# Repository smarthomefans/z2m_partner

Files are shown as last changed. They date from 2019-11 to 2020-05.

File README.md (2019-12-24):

# [中文文档](https://bbs.iobroker.cn/t/topic/882)

# z2m hardware module

This is hardware module for [iobroker.zigbee](https://github.com/ioBroker/ioBroker.zigbee) and [zigbee2mqtt](https://github.com/Koenkk/zigbee2mqtt) or [Zigbee to Tasmota](https://github.com/arendst/Tasmota/wiki/Zigbee).  
If you can speak Chinese and be interested with this project, please look at this [post](https://bbs.iobroker.cn/t/topic/882/33) in [ioBroker China BBS](https://bbs.iobroker.cn/)

## **V2P1 version is ready to ship**

## What's the difference

- Use [E18-MS1PA1-IPX](http://www.ebyte.com/en/product-view-news.aspx?id=123) zigbee module. 20dBm power can make sure zigbee net work signal is strong.
- Add an ESP8266 module. Give you another option that can connect zigbee module though wifi-to-serial (I was using this [project](https://github.com/smarthomefans/ESP32-Serial-Bridge)).
If your machine running smarthome platform, such as ioBroker or homeassistant, is put in a hidden corner, for better signal coverage, you can put your zigbee module in some where else.
- ESP8266 connected to E18 firmware download pins, give you a chance that can update E18 though ESP8266, no need to use CC-DEBUG.
- There will be 4 options for different TTY connection:
  - USB TTY <==> ESP 8266 TTY. This option is used for download firmware for E18.
  - USB TTY <==> E18 TTY. If you can connect your module though USB wire, this is more stable.
  - USB TTY <==> ESP 8266 debug port. ESP 8266 TTY <==> E18 TTY. Connect though wifi, and you can capture debug infomation though USB TTY.
  - ESP 8266 TTY <==> E18 TTY. Connect though TTY.

## Hardware module images

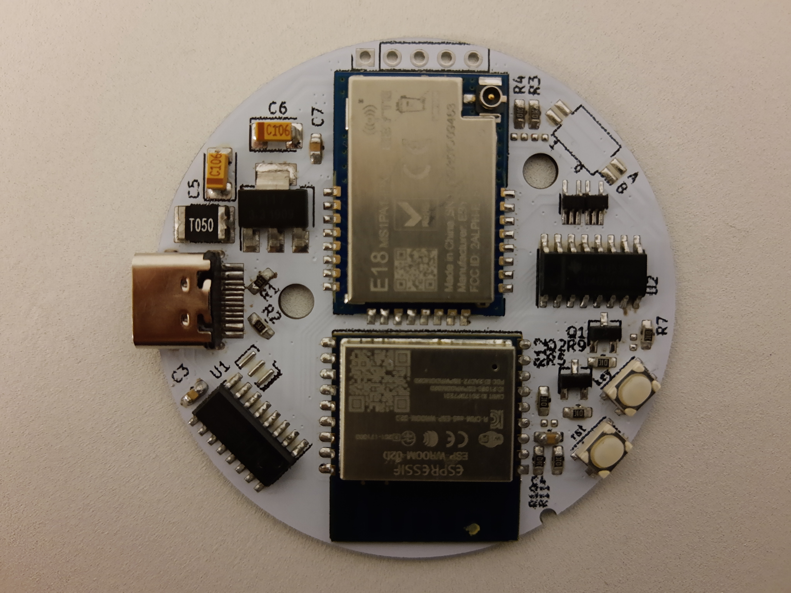
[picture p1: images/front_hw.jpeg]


## 3D cover

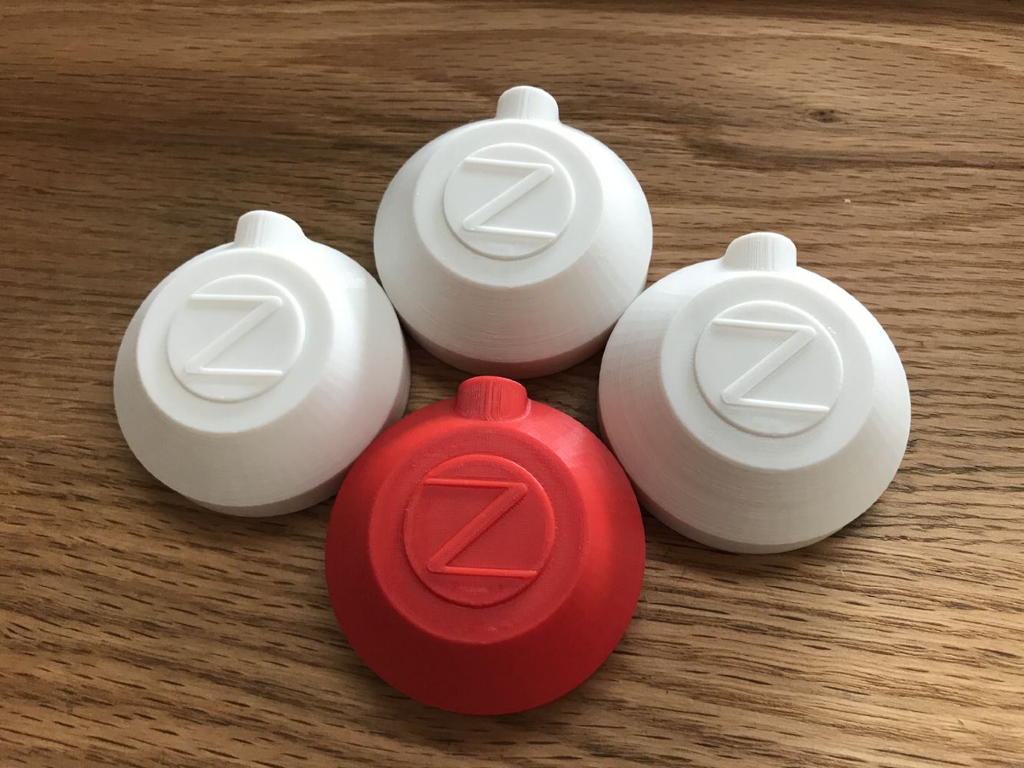
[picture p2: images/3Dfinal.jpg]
cave


## [SCH](https://github.com/smarthomefans/z2m_partner/raw/master/project/z2m_partner.pdf) preview
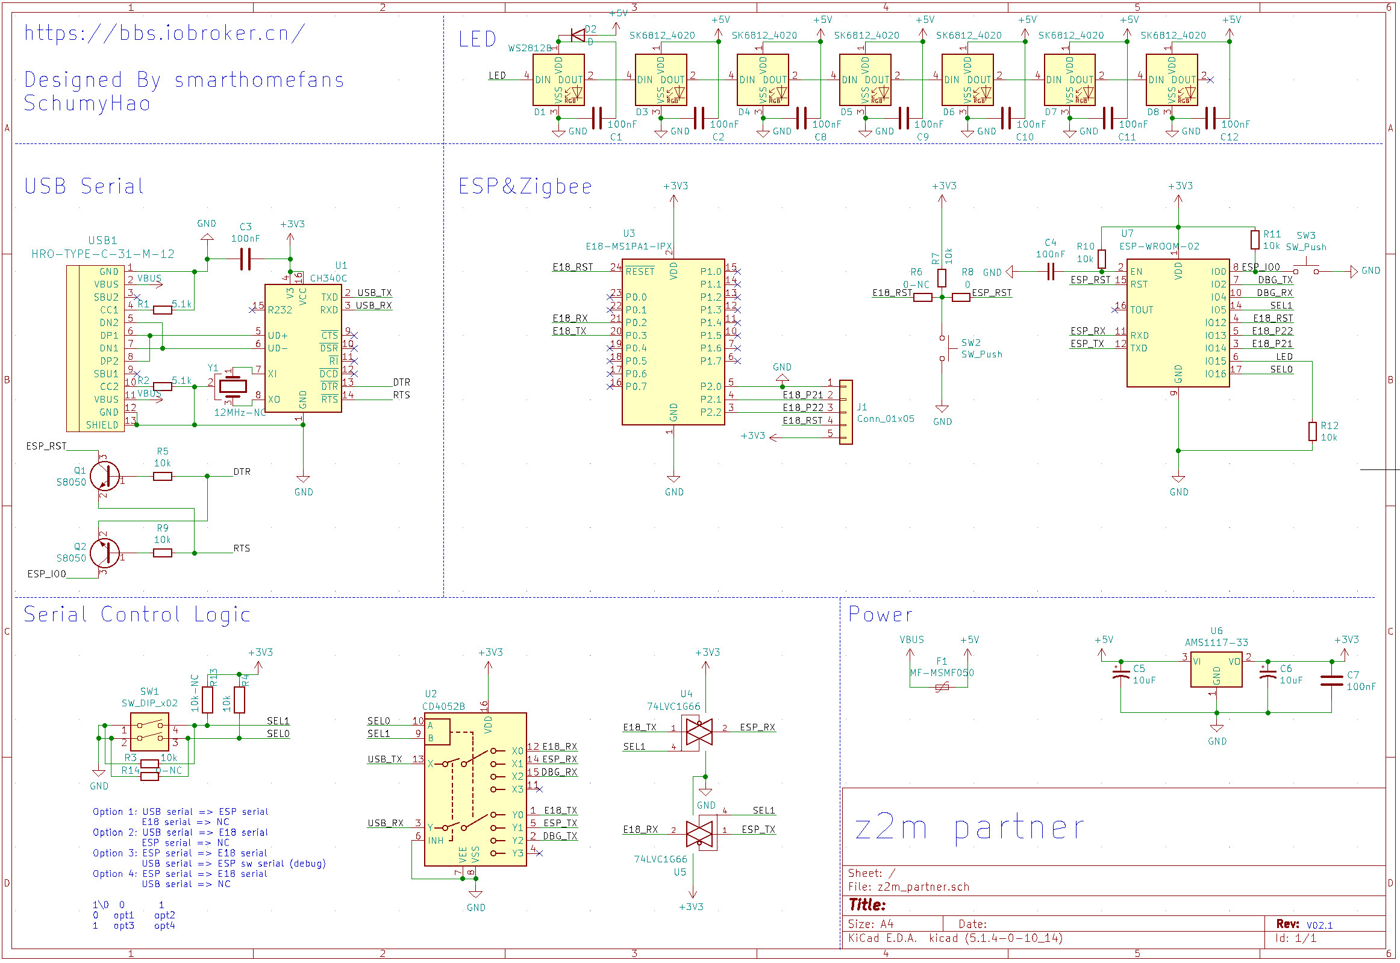
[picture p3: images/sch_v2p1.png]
sch view


## PCB preview

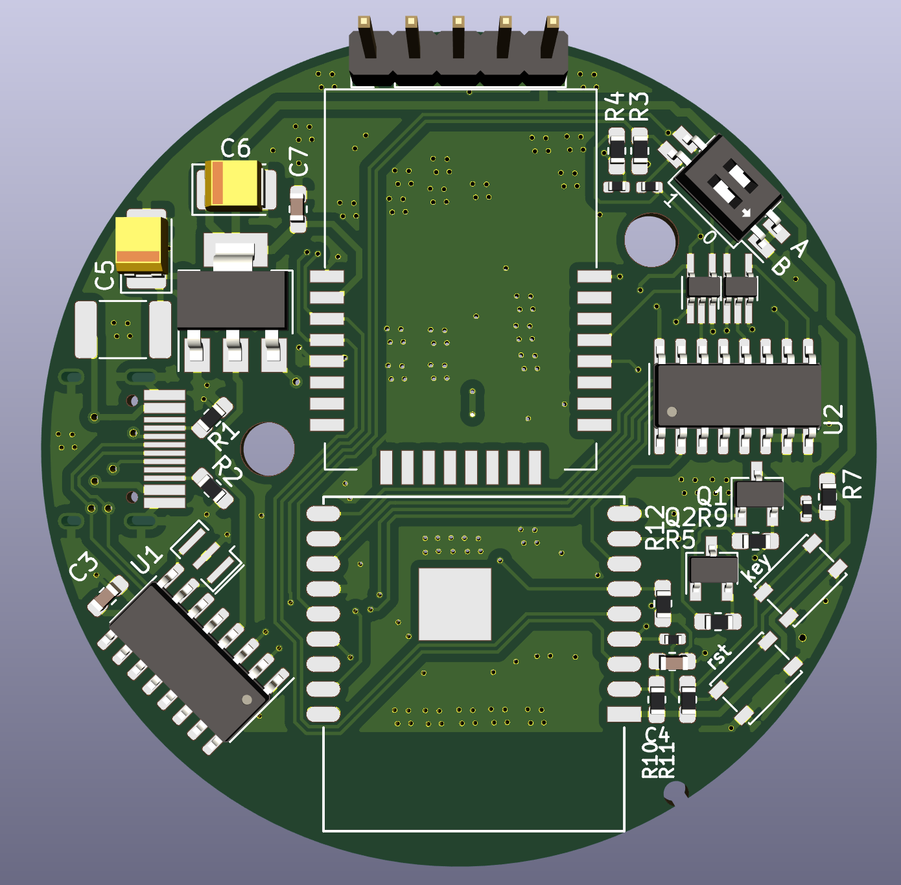
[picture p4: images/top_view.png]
top view

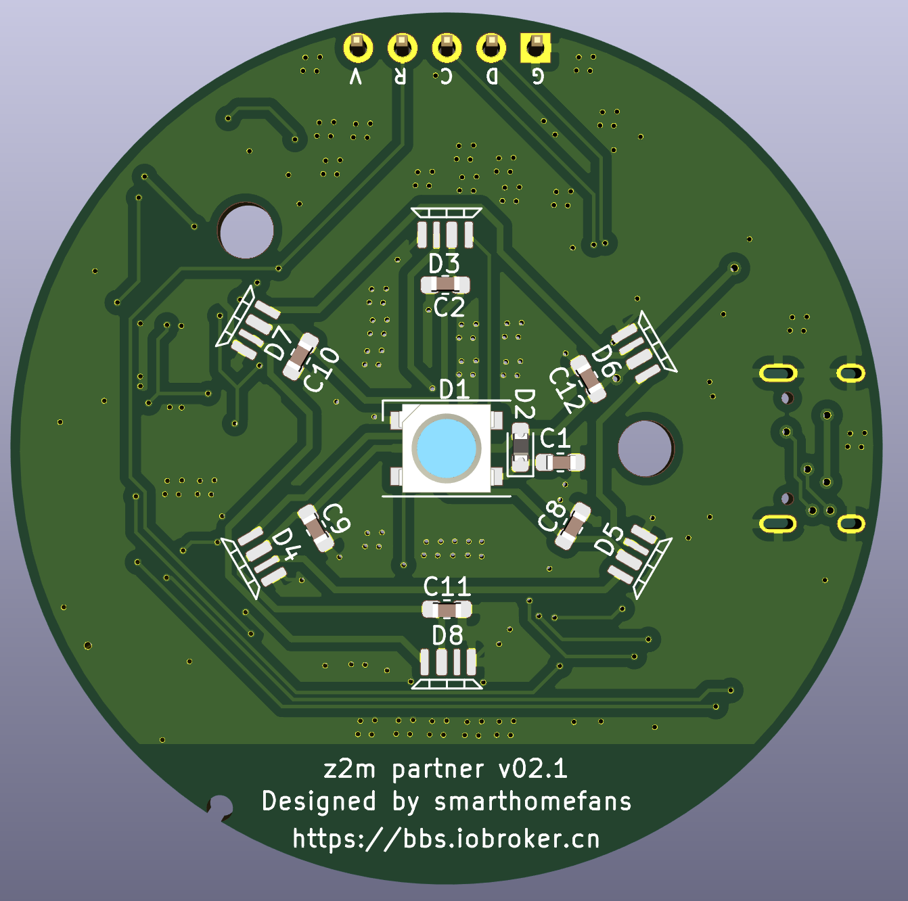
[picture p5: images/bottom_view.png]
bottom view


## BOM list
[BOM](https://github.com/smarthomefans/z2m_partner/blob/master/documents/bom.md) can get from here.

## Thanks to

- [modkam](https://modkam.ru/), [kirovilya](https://github.com/kirovilya), [Koenkk](https://github.com/Koenkk).

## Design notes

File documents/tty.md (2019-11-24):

# Z2M USB串口复用控制

## V01版本

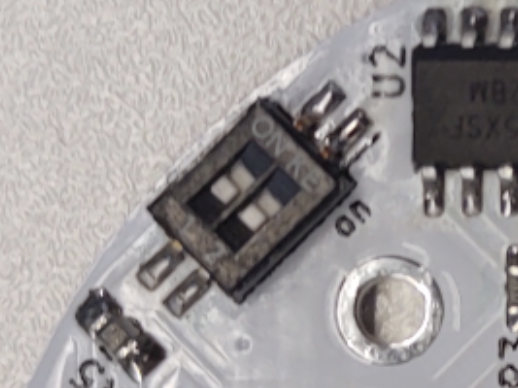
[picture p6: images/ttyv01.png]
switchv01


### 开关名称和状态定义

- 定义开关为上、下两个开关.
- 开关分别有左、右两种状态.

(就是别看板子上的丝印了)

### 工作模式对照表

-|上左|上右
---|---|---
下左|ESP连Zigbee, USB串口没有输出|ESP连Zigbee, USB串口输出调试信息
下右|USB串口连接Zigbee|USB串口连接ESP

## V02版本(未测试)

此版本目的是要不需要用户控制, 完全用ESP模块来控制串口复用状态.
所以, 请不焊接SW1, R13, R14, R3, R4.  
如果焊接了SW1, 也别焊接R3, R4, 并且保持SW1的两个开关都处于左测.

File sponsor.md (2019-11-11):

# Thanks to everyone who loves this project

# 感谢每一个喜欢这个项目的人

- li***36   6.66￥

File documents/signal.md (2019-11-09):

# E18系列模组信号测量结果

我使用频谱仪实际测量了不同的固件情况下, E18两款模组[E18-MS1PA1-IPX](http://www.ebyte.com/en/product-view-news.aspx?id=123)和[E18-2G4Z27SI](http://www.ebyte.com/en/product-view-news.aspx?id=522)发射时实际功率值.

在[Koenkk zigbee2mqtt](https://github.com/Koenkk/Z-Stack-firmware/tree/master/coordinator/Z-Stack_Home_1.2)使用的修订版ZNP固件中, 默认提供的CC2530+CC2592固件, 设置TX发射功率为[TX_PWR_PLUS_19](https://github.com/Koenkk/Z-Stack-firmware/blob/master/coordinator/Z-Stack_Home_1.2/firmware.patch#L328). 但是CC2592的手册说明此PA是可以21dBm发射的.

我发现TI源码中, 设置Tx发射功率的enum数据类型最大只定义到了19dBm, 揣测可能Koenkk就是使用了默认的最大值, 而没有根据不同PA进行设置.

我修改ZNP源码并编译, 得到了不同情况下的发射信号功率图.

## 默认固件

[E18-MS1PA1-IPX](http://www.ebyte.com/en/product-view-news.aspx?id=123)和[E18-2G4Z27SI](http://www.ebyte.com/en/product-view-news.aspx?id=522)情况一样. 实测发射功率为14.202dBm.
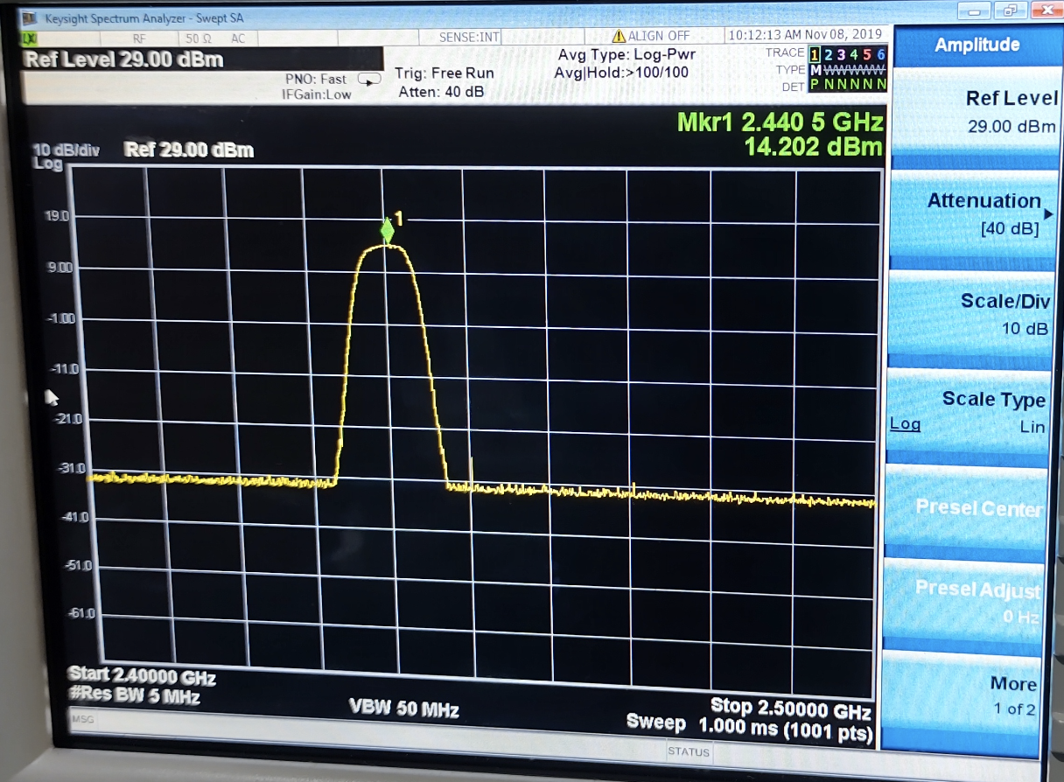
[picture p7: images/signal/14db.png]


## 修改21dBm

[E18-MS1PA1-IPX](http://www.ebyte.com/en/product-view-news.aspx?id=123)模组, 设置发射功率为2592最大功率21dBm. 代码修改如下:

```C
-      ZMacSetTransmitPower(TX_PWR_PLUS_19);
+      ZMacSetTransmitPower(21);
```

实测发射功率18.495dBm.
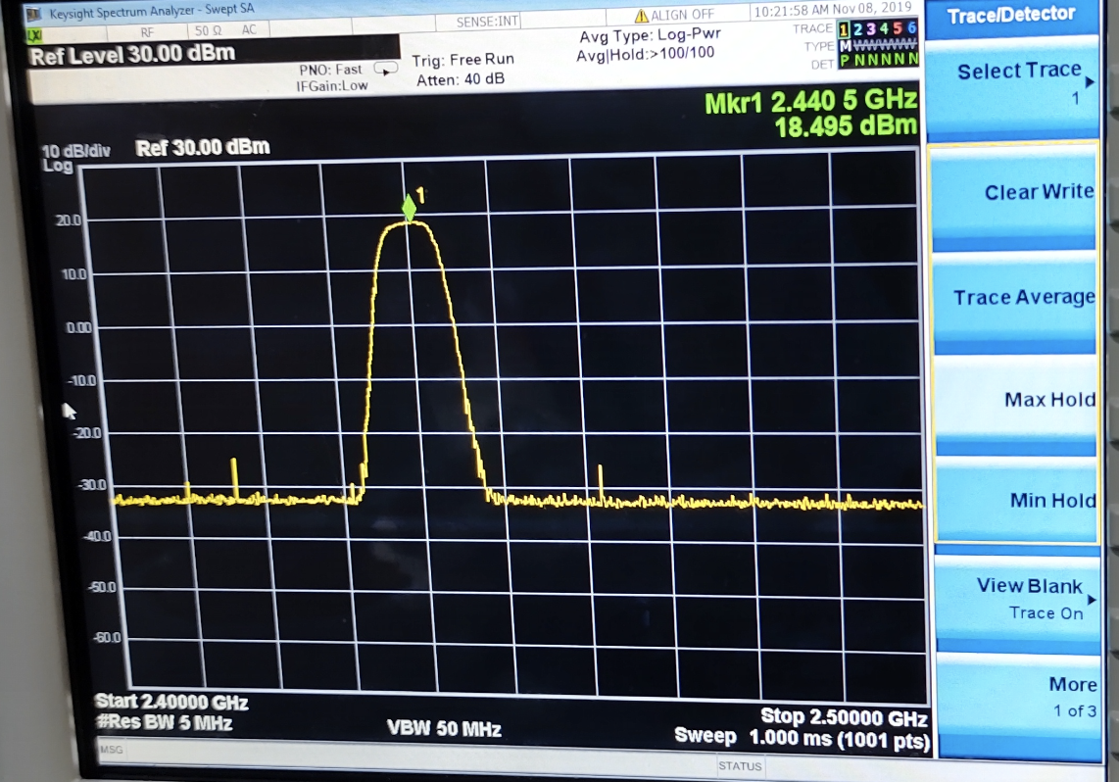
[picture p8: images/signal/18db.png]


## 修改27dBm

[E18-2G4Z27SI](http://www.ebyte.com/en/product-view-news.aspx?id=522)模组, 设置模组最大功率27dBm. 代码修改如下:

```C
-      ZMacSetTransmitPower(TX_PWR_PLUS_19);
+      ZMacSetTransmitPower(27);
```

实测发射功率26.809dBm.
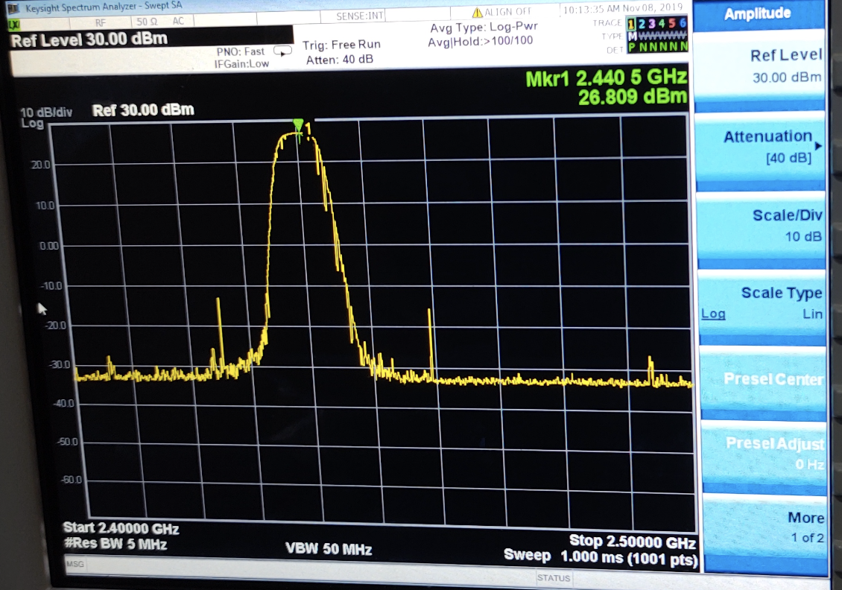
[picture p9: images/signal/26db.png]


## 总结

从频谱仪的实测结果来看, 要达到最大发射功率的话, 必须要修改固件源码才行. 我并不是专业硬件人员, 对于这个结果, 我又两点疑问:

1. 最大发射功率情况下, 明显能看到谐波的毛刺, 这个毛刺会不会对数据有干扰?
2. 修改的都是最大发射功率, 但是实际使用时, zigbee传感器会向网关发数据, 这时候网关是接收状态. 我们没办法修改小米等zigbee传感器, 是不是在这个情况下, 只增大网关的发射功率, 对双向传输的zigbee协议, 是不是太大帮助?

如果有专业人士可以帮忙解答, 麻烦提issue回答一下, 先表感谢.

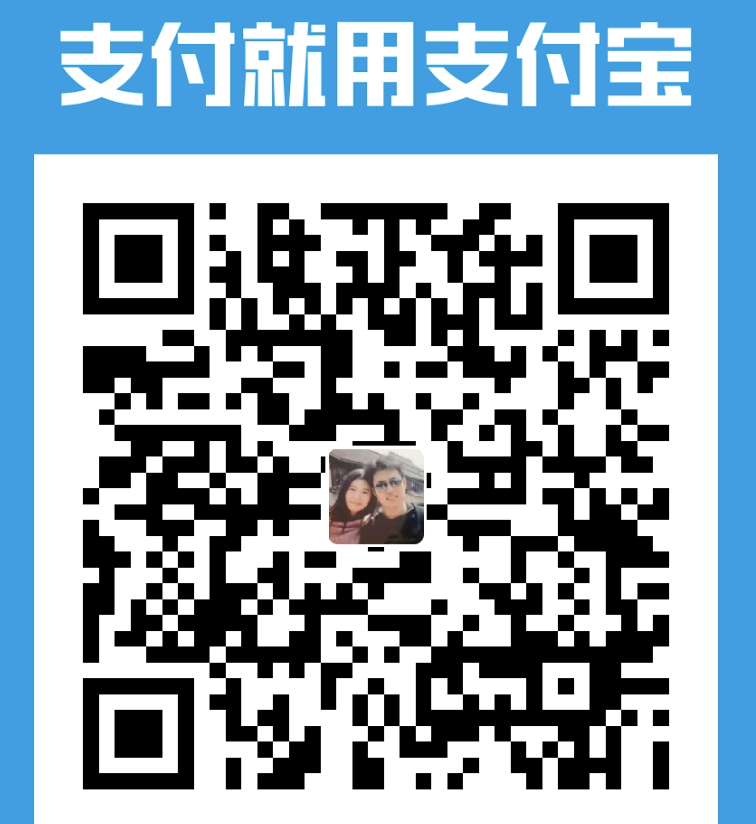
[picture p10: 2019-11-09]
images/pay/alipay.png

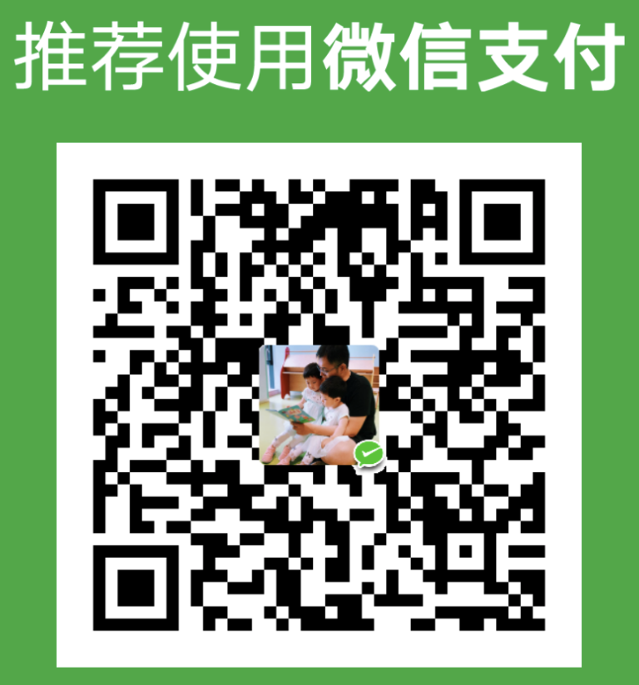
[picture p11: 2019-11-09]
images/pay/wechat.png

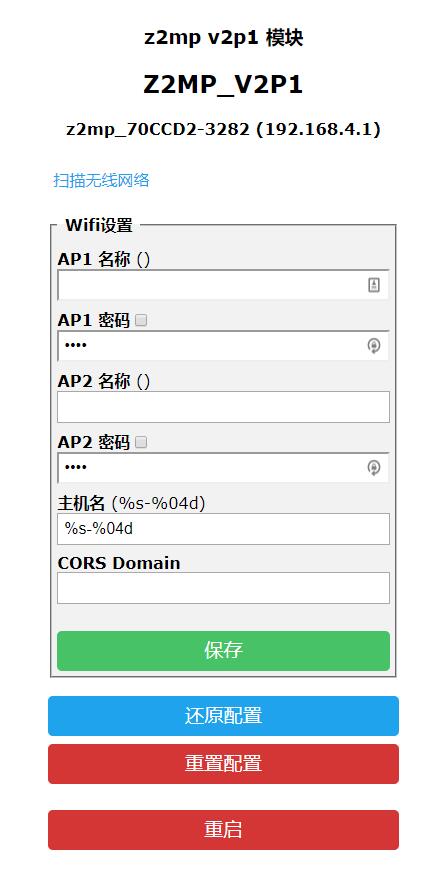
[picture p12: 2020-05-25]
images/tasmota/wifi_config.jpg

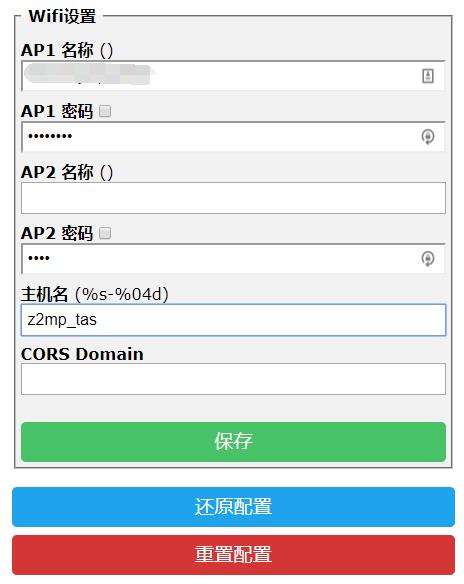
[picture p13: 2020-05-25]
images/tasmota/wifi_config2.jpg

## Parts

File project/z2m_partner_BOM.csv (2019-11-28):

Comment | Description | Designator | Footprint | LibRef | Pins | Quantity | PartNumber | url
100nF | desc | C3,C4,C7, | C_0603_1608Metric_Pad1.05x0.95mm_HandSolder | libref | 2 | 3 |  | ~
10uF | desc | C5,C6, | CP_EIA-3528-21_Kemet-B_Pad1.50x2.35mm_HandSolder | libref | 2 | 2 |  | ~
MF-MSMF050 | desc | F1, | Fuse_1812_4532Metric_Pad1.30x3.40mm_HandSolder | libref | 2 | 1 |  | ~
S8050 | desc | Q1,Q2, | TSOT-23 | libref | 3 | 2 |  | ~
5.1k | desc | R1,R2, | R_0603_1608Metric_Pad1.05x0.95mm_HandSolder | libref | 2 | 2 |  | ~
10k-NC | desc | R13, | R_0402_1005Metric | libref | 2 | 1 |  | ~
10k | desc | R4,R7,R10,R11,R12,R5,R9,R3, | R_0603_1608Metric_Pad1.05x0.95mm_HandSolder | libref | 2 | 8 |  | ~
0-NC | desc | R6,R14, | R_0402_1005Metric | libref | 2 | 2 |  | ~
0 | desc | R8, | R_0402_1005Metric | libref | 2 | 1 |  | ~
SW_DIP_x02 | desc | SW1, | SW_DIP_SPSTx02_Slide_Copal_CHS-02B_W7.62mm_P1.27mm | libref | 4 | 1 |  | ~
SW_Push | desc | SW2,SW3, | SW_SPST_PTS810 | libref | 4 | 2 |  | ~
CH340C | desc | U1, | SOIC-16_3.9x9.9mm_P1.27mm | libref | 16 | 1 |  | http://www.datasheet5.com/pdf-local-2195953
CD4052B | desc | U2, | SOIC-16_3.9x9.9mm_P1.27mm | libref | 16 | 1 |  | http://www.ti.com/lit/ds/symlink/cd4052b.pdf
E18-MS1PA1-IPX | desc | U3, | E18-MS1PA1-IPX | libref | 24 | 1 |  | http://www.cdebyte.com/en/downpdf.aspx?id=122
74LVC1G66 | desc | U4,U5, | SOT-353_SC-70-5_Handsoldering | libref | 5 | 2 |  | http://www.ti.com/lit/sg/scyt129e/scyt129e.pdf
AMS1117-33 | desc | U6, | SOT-223-3_TabPin2 | libref | 4 | 1 |  | http://www.diodes.com/datasheets/AP1117.pdf
ESP-WROOM-02 | desc | U7, | ESP-13-WROOM-02 | libref | 19 | 1 |  | https://www.espressif.com/sites/default/files/documentation/0c-esp-wroom-02_datasheet_en.pdf
12MHz-NC | desc | Y1, | Resonator_SMD_muRata_CSTxExxV-3Pin_3.0x1.1mm | libref | 3 | 1 |  | ~
100nF | desc | C1,C2,C8,C9,C10,C11,C12, | C_0603_1608Metric_Pad1.05x0.95mm_HandSolder | libref | 2 | 7 |  | ~
WS2812B | desc | D1, | LED_WS2812B_PLCC4_5.0x5.0mm_P3.2mm | libref | 4 | 1 |  | https://cdn-shop.adafruit.com/datasheets/WS2812B.pdf
D | desc | D2, | D_0603_1608Metric_Pad1.05x0.95mm_HandSolder | libref | 2 | 1 |  | ~
SK6812_4020 | desc | D3,D4,D5,D6,D7,D8, | SK6812_4020 | libref | 4 | 6 |  | https://cdn-shop.adafruit.com/datasheets/WS2812B.pdf
Through Hole Items
Conn_01x05 | desc | J1, | PinHeader_1x05_P2.54mm_Vertical | libref | 5 | 1 |  | ~
MountingHole_3.2mm_M3_ISO14580 | desc | REF**,REF**, | MountingHole_3.2mm_M3_ISO14580 | libref | 1 | 2
HRO-TYPE-C-31-M-12 | desc | USB1, | HRO-TYPE-C-31-M-12-HandSoldering | libref | 18 | 1

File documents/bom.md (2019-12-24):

## BOM单

### 做WiFi/USB有线接入的Zigbee网关

名称|封装|数值|数量|标号|立创商城货号
---|---|---|---|---|---
贴片钽电容|TypeB|10uF|2|C5, C6|[C128257](https://item.szlcsc.com/139542.html)
贴片电容|0603|100nF|3|C3, C4, C7|[C149620](https://item.szlcsc.com/160954.html)
自恢复限流保险|1812|MF-MSMF050|1|F1|[C17313](https://item.szlcsc.com/17998.html)
贴片电阻|0603|5.1k|2|R1, R2|[C26000](https://item.szlcsc.com/26743.html)
贴片电阻|0603|10k|8|R3, R4, R5, R7, R9-R12|[C15401](https://item.szlcsc.com/16079.html)
微动开关|SW_SPST_PTS810|SW_Push|2|SW2, SW3|[C221896](https://item.szlcsc.com/222326.html)
USB串口芯片|SOP16|CH340C|1|U1|[C84681](https://item.szlcsc.com/85852.html)
模拟开关芯片|SOP16|CD4052B|1|U2|[C6521](https://item.szlcsc.com/6986.html)
Zigbee模块|E18-MS1PA1-IPX|E18-MS1PA1-IPX|1|U3|[C108551](https://item.szlcsc.com/109770.html)
模拟开关芯片|SOT-353|74LVC1G66|2|U4, U5|[C113518](https://list.szlcsc.com/catalog/488.html)
低压差线性稳压器|SOT-223-3|1117-33|1|U6|[C369933](https://list.szlcsc.com/catalog/387.html)
WiFi模块|ESP-WROOM-02|ESP-WROOM-02|1|U7|[C81770](https://item.szlcsc.com/82923.html)
SMA转I-PEX|||1||[C403729](https://item.szlcsc.com/389816.html)
TypeC座|||1||[C165948](https://item.szlcsc.com/177331.html)
三极管|SOT-23|S8050|2|Q1,Q2|[C181158](https://item.szlcsc.com/192555.html)
胶棒天线||2.4G|1||[C381198](https://item.szlcsc.com/353456.html)

参考价格来自立创商城. 加上PCB成本, 总计成本约**68.236**元.

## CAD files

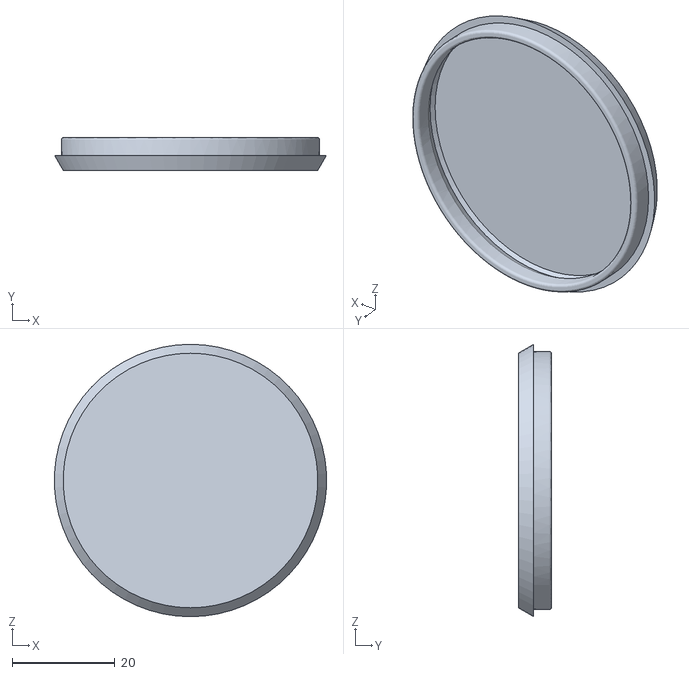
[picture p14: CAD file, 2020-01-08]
3D/v02p1/Zigbee网关-C.STL
52.9 x 6.50 x 53.0

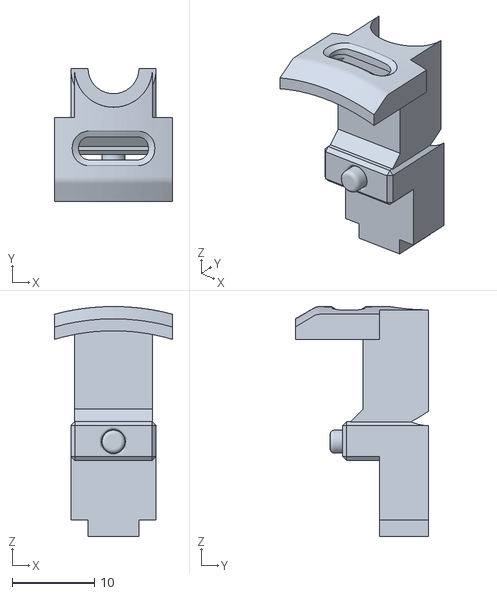
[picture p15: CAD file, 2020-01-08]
3D/v02p1/Zigbee网关-B.STL
14.4 x 16.2 x 28.0

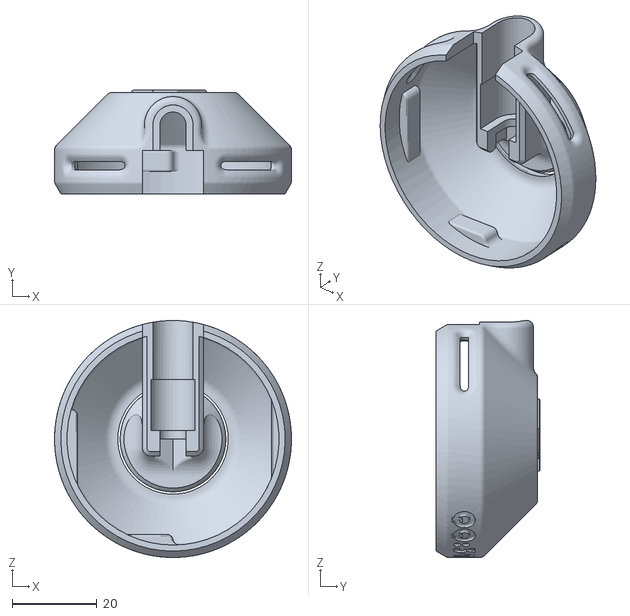
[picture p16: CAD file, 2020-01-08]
3D/v02p1/Zigbee网关-A.STL
56.0 x 24.5 x 56.0

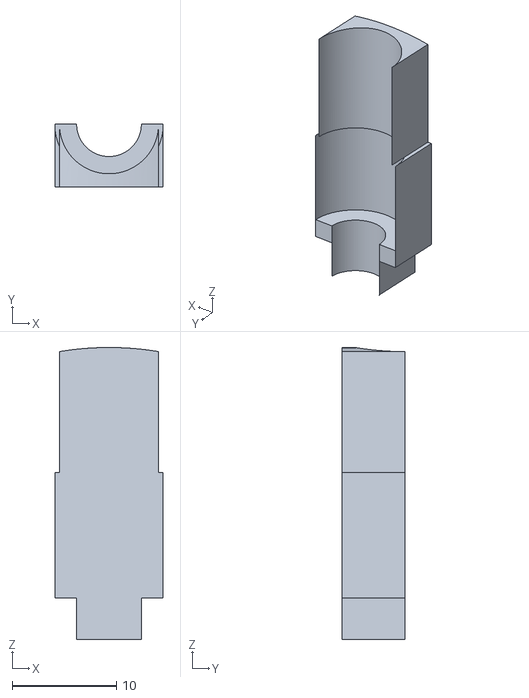
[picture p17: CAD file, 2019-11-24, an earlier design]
3D/v01/Zigbee网关-B.STL
10.4 x 6.00 x 28.0

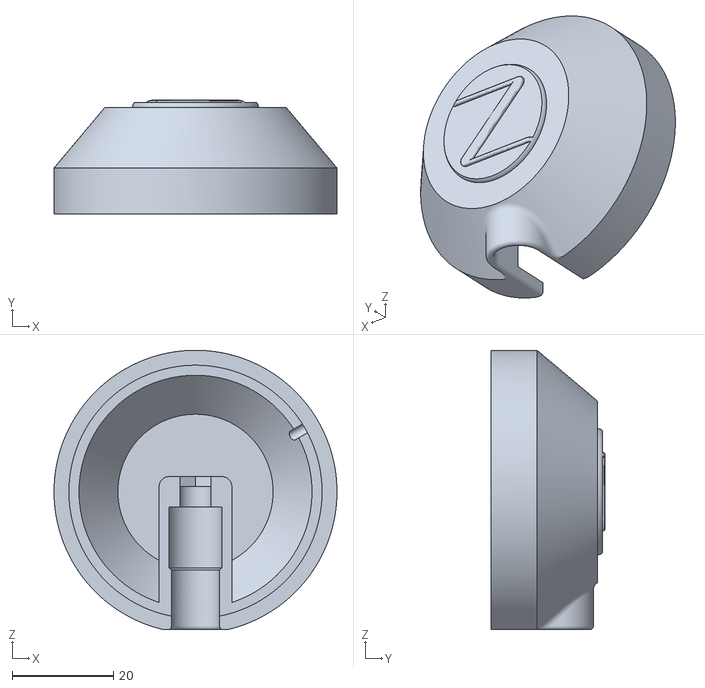
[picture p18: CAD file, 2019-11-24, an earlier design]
3D/v01/Zigbee网关-A.STL
56.0 x 22.5 x 55.3

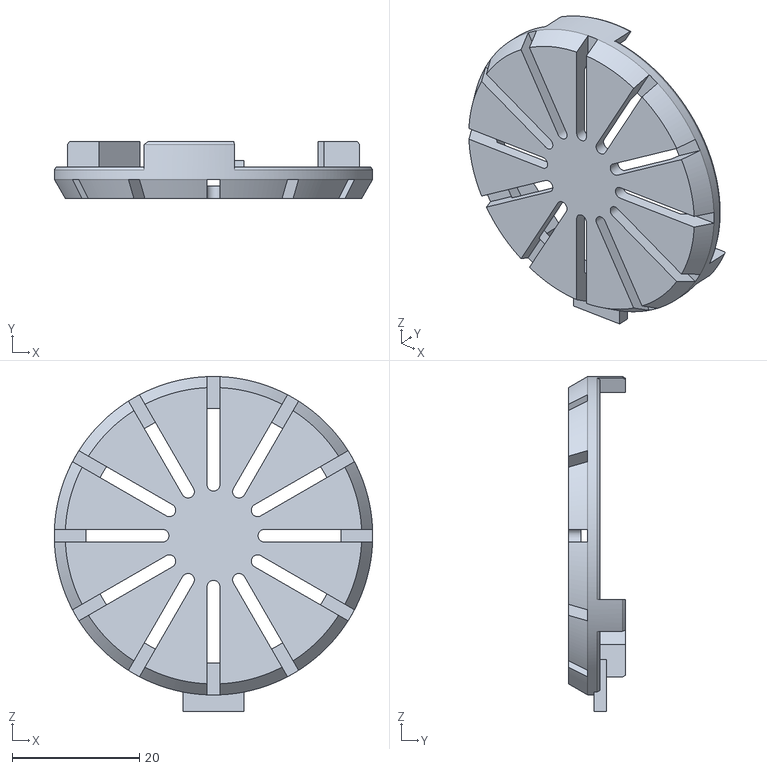
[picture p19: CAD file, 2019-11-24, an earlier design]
3D/v01/Zigbee网关-C.STL
50.0 x 9.00 x 52.6

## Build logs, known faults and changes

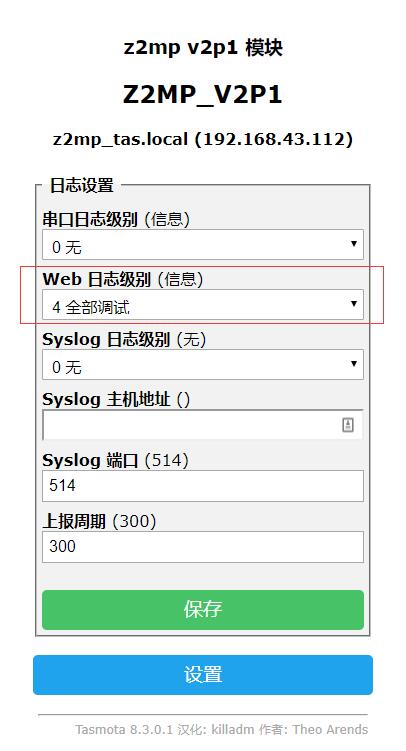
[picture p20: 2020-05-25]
images/tasmota/set_debug.jpg

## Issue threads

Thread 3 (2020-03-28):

关于一个网关的设备上限问题

hzx1987227, 2020-03-28:
首先感谢您提供如此优秀的开源硬件.

我有一个疑问关于单一网关设备上限的问题,

我添加了17个设备后,无法再添加任何设备.(添加设备时无pair信息显示)

(包括了几个单火墙开被识别成router的,

但是官方device.js文档好象有提到单火设备无法成为router)

而查阅官方网站后得知CC2530/2531默认固件是支持20个设备.

我一个朋友反馈的情况也是和我一样,同样是17个设备以后无法再添加新设备.

请问我们现在的硬件和固件的单一网关设备上限是否就是17呢?

单火墙开到底是否能成为router?

谢谢

hzx1987227, 2020-03-29:
已找到答案

参考:https://github.com/Koenkk/Z-Stack-firmware/tree/master/coordinator

Closed 2020-03-29.

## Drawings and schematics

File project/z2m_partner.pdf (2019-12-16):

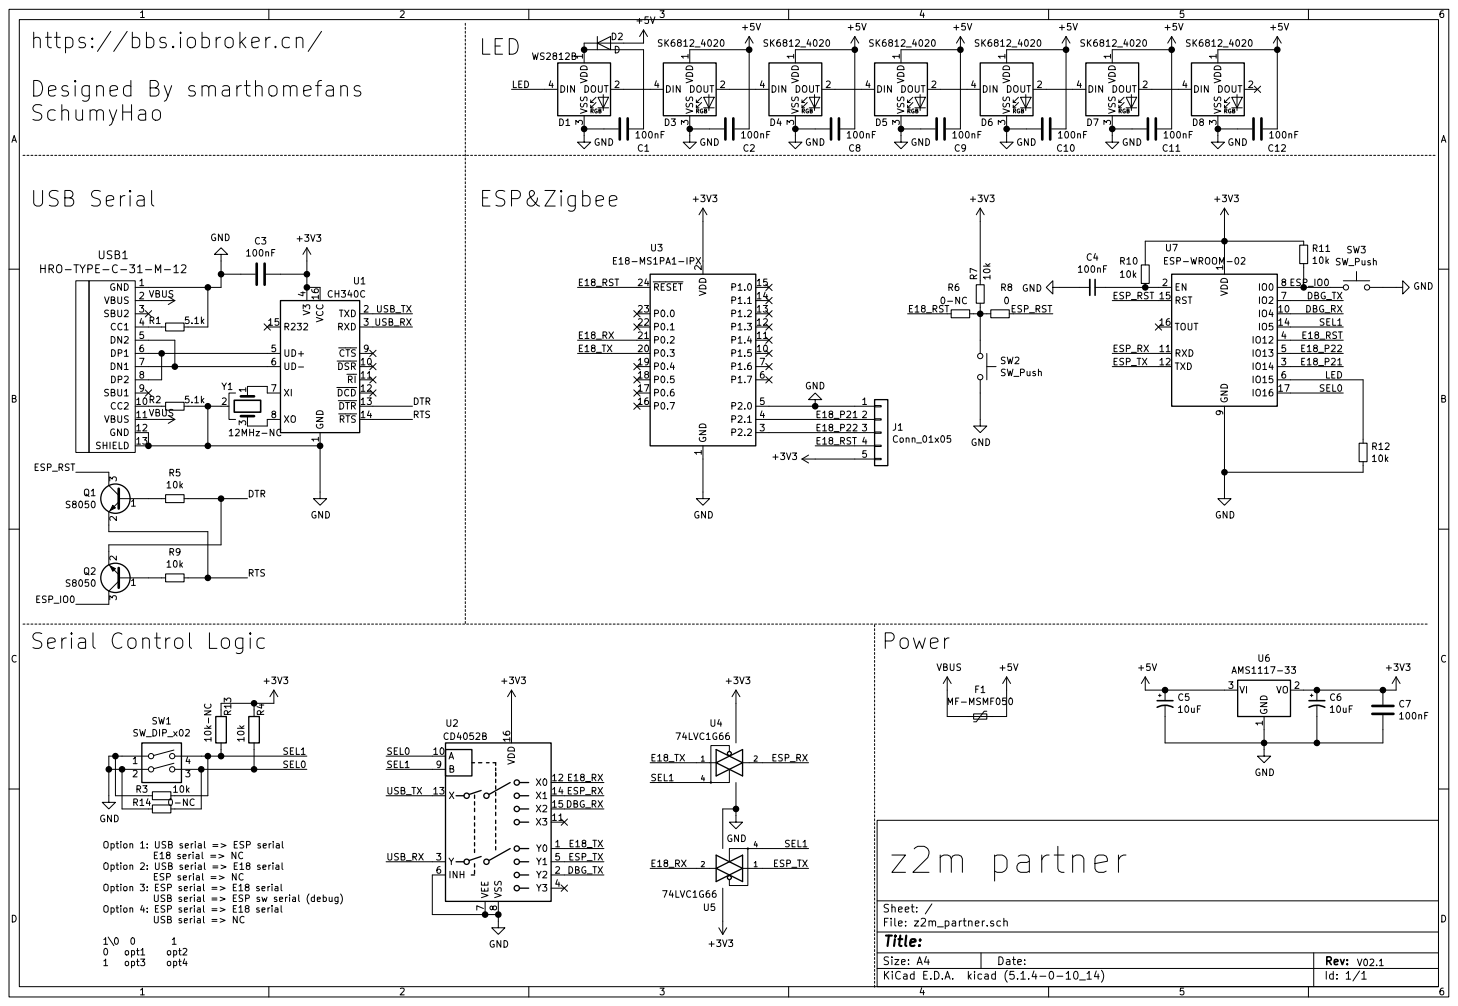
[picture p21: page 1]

https://bbs.iobroker.cn/
Designed By smarthomefans
SchumyHao

4 UD+ 5 UD- 6 XI 7 XO 8 CTS 9 U1 CH340C

1 DSR 10 RI 11 DCD 12 DTR 13 RTS 14 R232 15 VCC 16 TXD 2 RXD 3 V3

Option 1: USB serial => ESP serial E18 serial => NC Option 2: USB serial => E18 serial ESP serial => NC Option 3: ESP serial => E18 serial

USB serial => ESP sw serial (debug)
Option 4: ESP serial => E18 serial USB serial => NC

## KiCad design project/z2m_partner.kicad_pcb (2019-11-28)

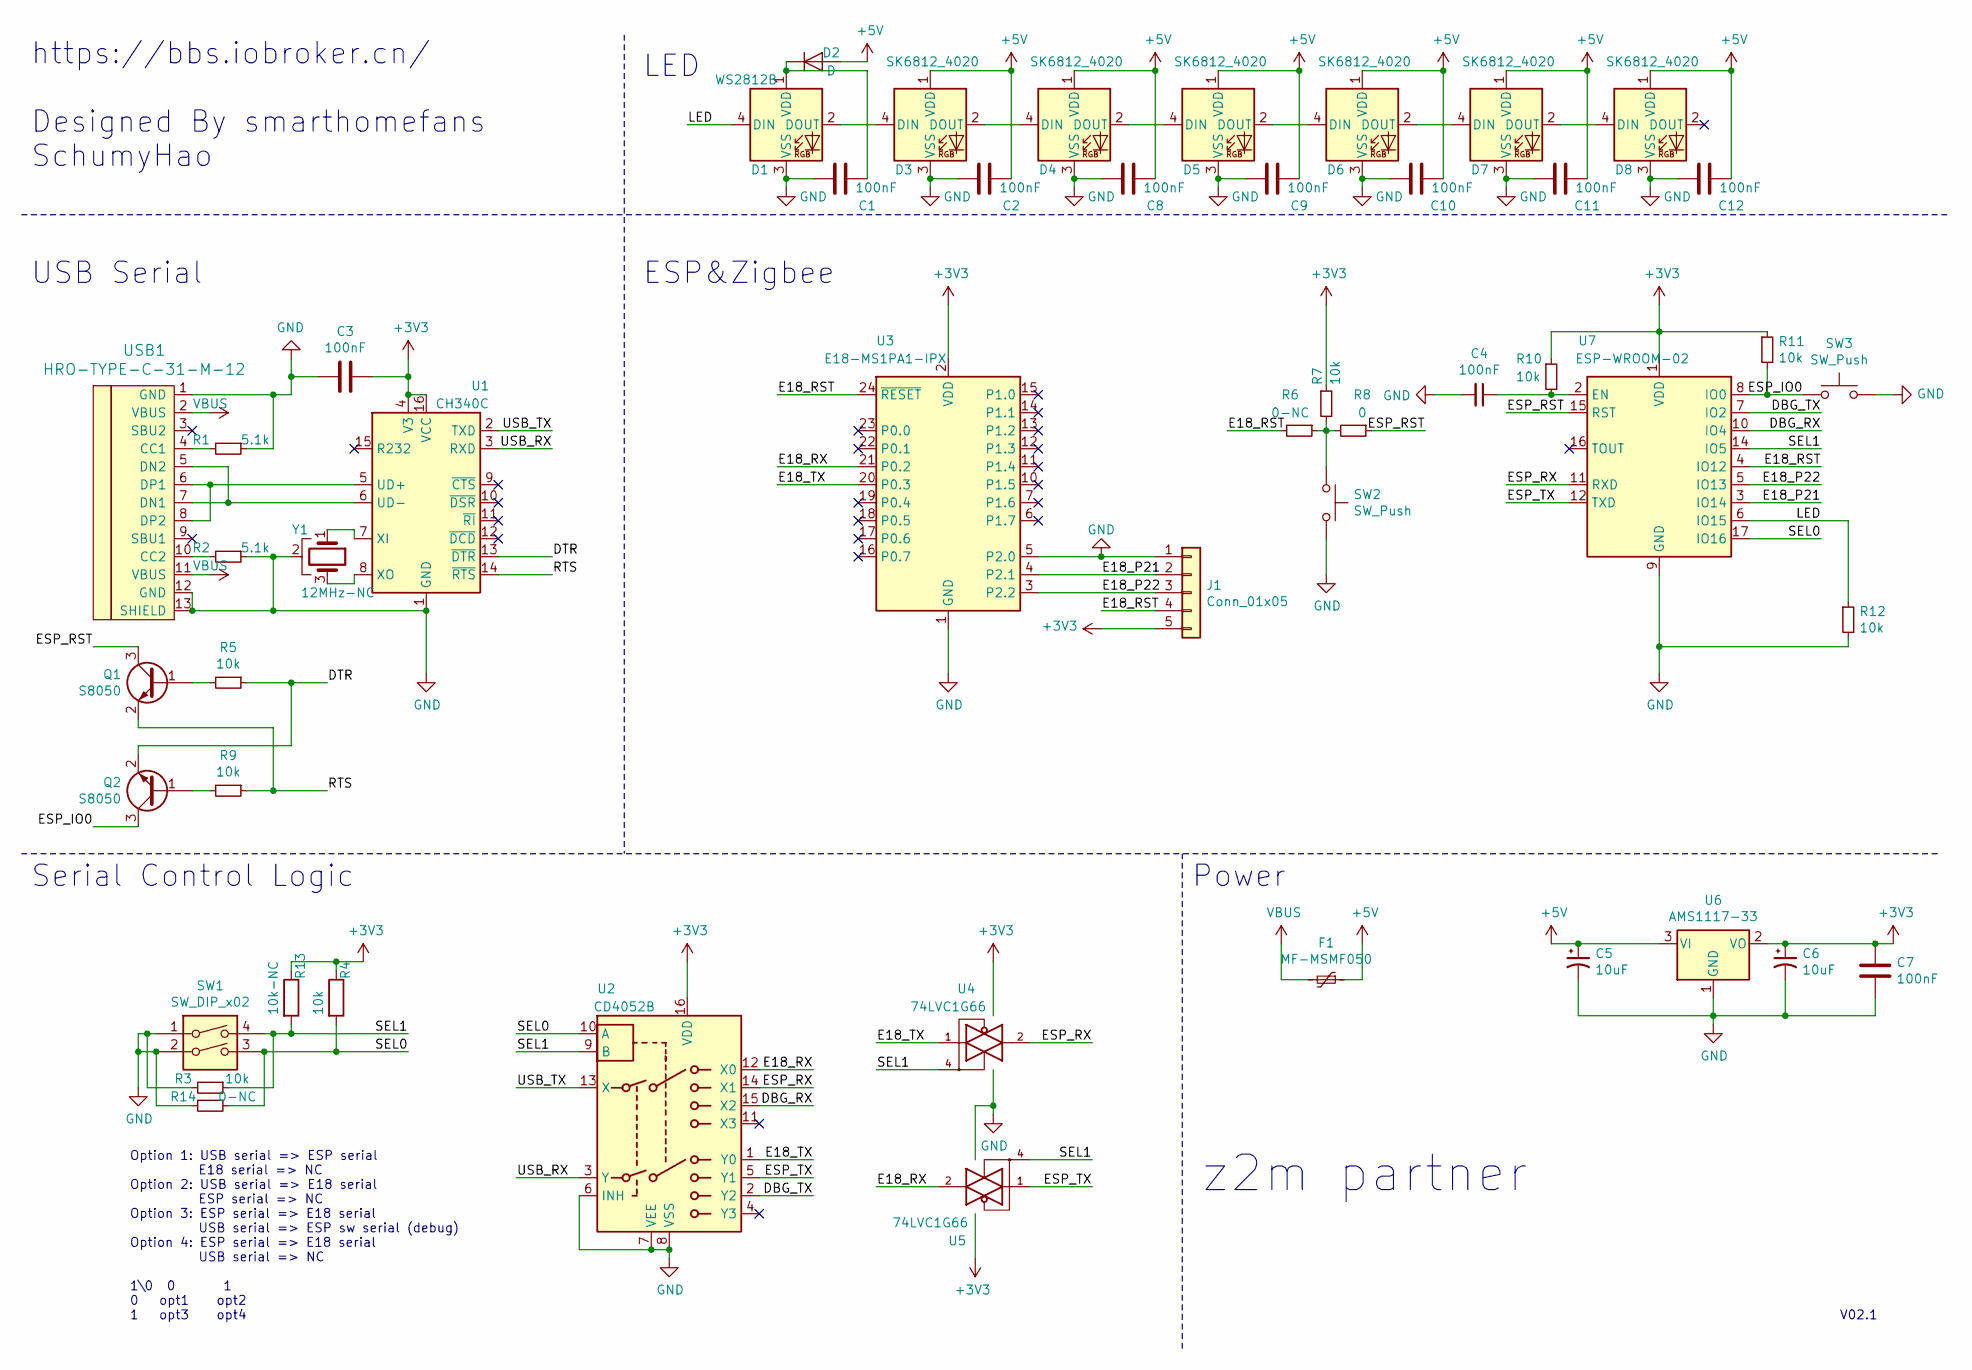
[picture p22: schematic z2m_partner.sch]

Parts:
C1, C2, C3, C4, C7, C8, C9, C10, C11, C12: 100nF; C_0603_1608Metric_Pad1.05x0.95mm_HandSolder
C5, C6: 10uF; CP_EIA-3528-21_Kemet-B_Pad1.50x2.35mm_HandSolder
D1: WS2812B; LED_WS2812B_PLCC4_5.0x5.0mm_P3.2mm
D2: D; D_0603_1608Metric_Pad1.05x0.95mm_HandSolder
D3, D4, D5, D6, D7, D8: SK6812_4020
F1: MF-MSMF050; Fuse_1812_4532Metric_Pad1.30x3.40mm_HandSolder
J1: Conn_01x05; PinHeader_1x05_P2.54mm_Vertical
Q1, Q2: S8050; TSOT-23
R1, R2: 5.1k; R_0603_1608Metric_Pad1.05x0.95mm_HandSolder
R3, R4, R5, R7, R9, R10, R11, R12: 10k; R_0603_1608Metric_Pad1.05x0.95mm_HandSolder
R6, R14: 0-NC; R_0402_1005Metric
R8: 0; R_0402_1005Metric
R13: 10k-NC; R_0402_1005Metric
SW1: SW_DIP_x02; SW_DIP_SPSTx02_Slide_Copal_CHS-02B_W7.62mm_P1.27mm
SW2, SW3: SW_Push; SW_SPST_PTS810
U1: CH340C; SOIC-16_3.9x9.9mm_P1.27mm
U2: CD4052B; SOIC-16_3.9x9.9mm_P1.27mm
U3: E18-MS1PA1-IPX
U4, U5: 74LVC1G66; SOT-353_SC-70-5_Handsoldering
U6: AMS1117-33; SOT-223-3_TabPin2
U7: ESP-WROOM-02; ESP-13-WROOM-02
USB1: HRO-TYPE-C-31-M-12; HRO-TYPE-C-31-M-12-HandSoldering
Y1: 12MHz-NC; Resonator_SMD_muRata_CSTxExxV-3Pin_3.0x1.1mm

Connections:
+3V3: C3.1, C6.1, C7.1, J1.5, R4.1, R7.1, R10.1, R11.1, R13.1, U1.4 (V3), U1.16 (VCC), U2.16 (VDD), U3.2 (VDD), U4.5 (VCC), U5.5 (VCC), U6.2 (VO), U7.1 (VDD)
+5V: C2.2, C5.1, C8.2, C9.2, C10.2, C11.2, C12.2, D2.2 (A), D3.1 (VDD), D4.1 (VDD), D5.1 (VDD), D6.1 (VDD), D7.1 (VDD), D8.1 (VDD), F1.1, U6.3 (VI)
/DBG_RX: U2.15 (X2), U7.10 (IO4)
/DBG_TX: U2.2 (Y2), U7.7 (IO2)
/DTR: Q2.2 (E), R5.1, U1.13 (~DTR)
/E18_P21: J1.2, U3.4 (P2.1), U7.3 (IO14)
/E18_P22: J1.3, U3.3 (P2.2), U7.5 (IO13)
/E18_RST: J1.4, R6.2, U3.24 (~RESET), U7.4 (IO12)
/E18_RX: U2.12 (X0), U3.21 (P0.2), U5.2
/E18_TX: U2.1 (Y0), U3.20 (P0.3), U4.1
/ESP_IO0: Q2.3 (C), R11.2, SW3.1, U7.8 (IO0)
/ESP_RST: Q1.3 (C), R8.1, U7.15 (RST)
/ESP_RX: U2.14 (X1), U4.2, U7.11 (RXD)
/ESP_TX: U2.5 (Y1), U5.1, U7.12 (TXD)
/LED: D1.4 (DIN), R12.1, U7.6 (IO15)
/RTS: Q1.2 (E), R9.1, U1.14 (~RTS)
/SEL0: R4.2, R14.1, SW1.3, U2.10 (A), U7.17 (IO16)
/SEL1: R3.1, R13.2, SW1.4, U2.9 (B), U4.4, U5.4, U7.14 (IO5)
/USB_RX: U1.3 (RXD), U2.3 (Y)
/USB_TX: U1.2 (TXD), U2.13 (X)
GND: C1.1, C2.1, C3.2, C4.2, C5.2, C6.2, C7.2, C8.1, C9.1, C10.1, C11.1, C12.1, D1.3 (VSS), D3.3 (VSS), D4.3 (VSS), D5.3 (VSS), D6.3 (VSS), D7.3 (VSS), D8.3 (VSS), J1.1, R1.1, R2.1, R3.2, R12.2, R14.2, SW1.1, SW1.2, SW2.2, SW3.2, U1.1 (GND), U2.6 (INH), U2.7 (VEE), U2.8 (VSS), U3.1 (GND), U3.5 (P2.0), U4.3 (GND), U5.3 (GND), U6.1 (GND), U7.9 (GND), U7.13 (GND), U7.18 (GND), U7.19 (GND), USB1.1 (GND), USB1.12 (GND), USB1.13 (SHIELD), Y1.2
unnamed: C1.2, D1.1 (VDD), D2.1 (K)
unnamed: C4.1, R10.2, U7.2 (EN)
unnamed: D1.2 (DOUT), D3.4 (DIN)
unnamed: D3.2 (DOUT), D4.4 (DIN)
unnamed: D4.2 (DOUT), D5.4 (DIN)
unnamed: D5.2 (DOUT), D6.4 (DIN)
unnamed: D6.2 (DOUT), D7.4 (DIN)
unnamed: D7.2 (DOUT), D8.4 (DIN)
unnamed: Q1.1 (B), R5.2
unnamed: Q2.1 (B), R9.2
unnamed: R1.2, USB1.4 (CC1)
unnamed: R2.2, USB1.10 (CC2)
unnamed: R6.1, R7.2, R8.2, SW2.1
unnamed: U1.5 (UD+), USB1.6 (DP1), USB1.8 (DP2)
unnamed: U1.6 (UD-), USB1.5 (DN2), USB1.7 (DN1)
unnamed: U1.7 (XI), Y1.1
unnamed: U1.8 (XO), Y1.3
VBUS: F1.2, USB1.2 (VBUS), USB1.11 (VBUS)

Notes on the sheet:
Option 1: USB serial => ESP serial E18 serial => NC Option 2: USB serial => E18 serial ESP serial => NC Option 3: ESP serial => E18 serial USB serial => ESP sw serial (debug) Option 4: ESP serial => E18 serial USB serial => NC 1\0 0 1 0 opt1 opt2 1 opt3 opt4
Serial Control Logic
Power
USB Serial
z2m partner
https://bbs.iobroker.cn/ Designed By smarthomefans SchumyHao
ESP&Zigbee
V02.1
LED

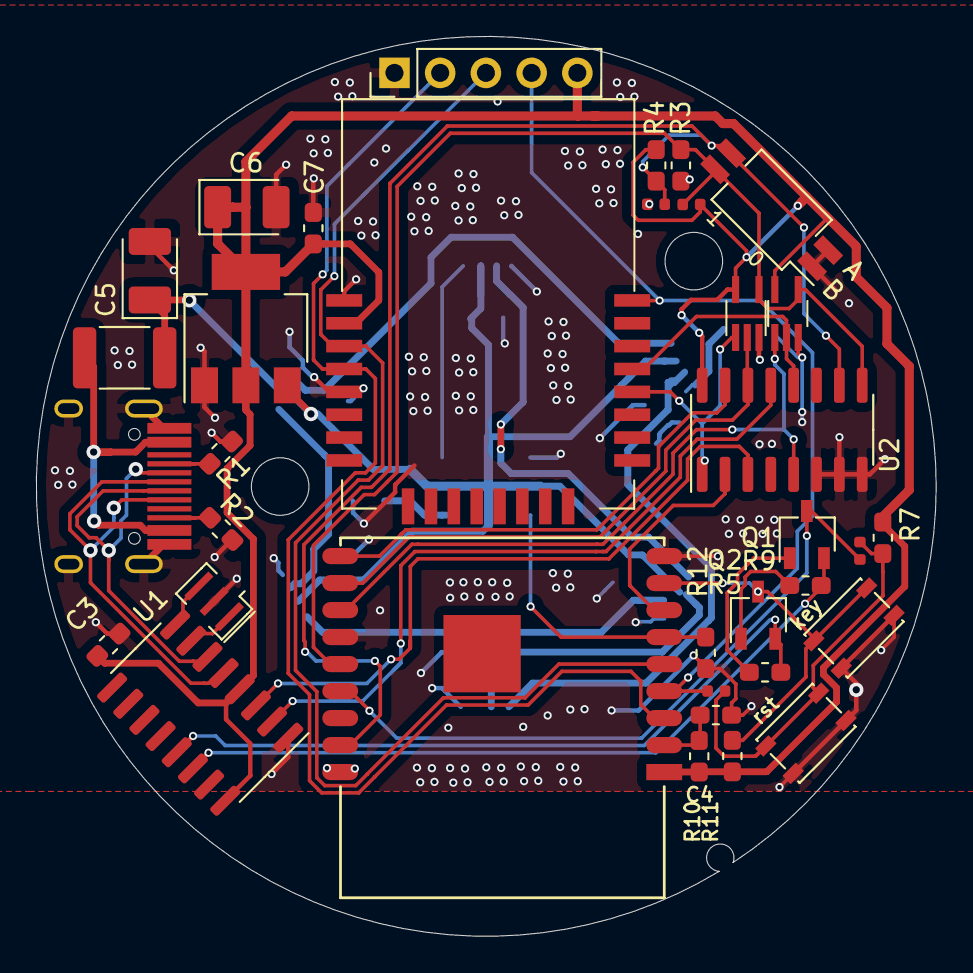
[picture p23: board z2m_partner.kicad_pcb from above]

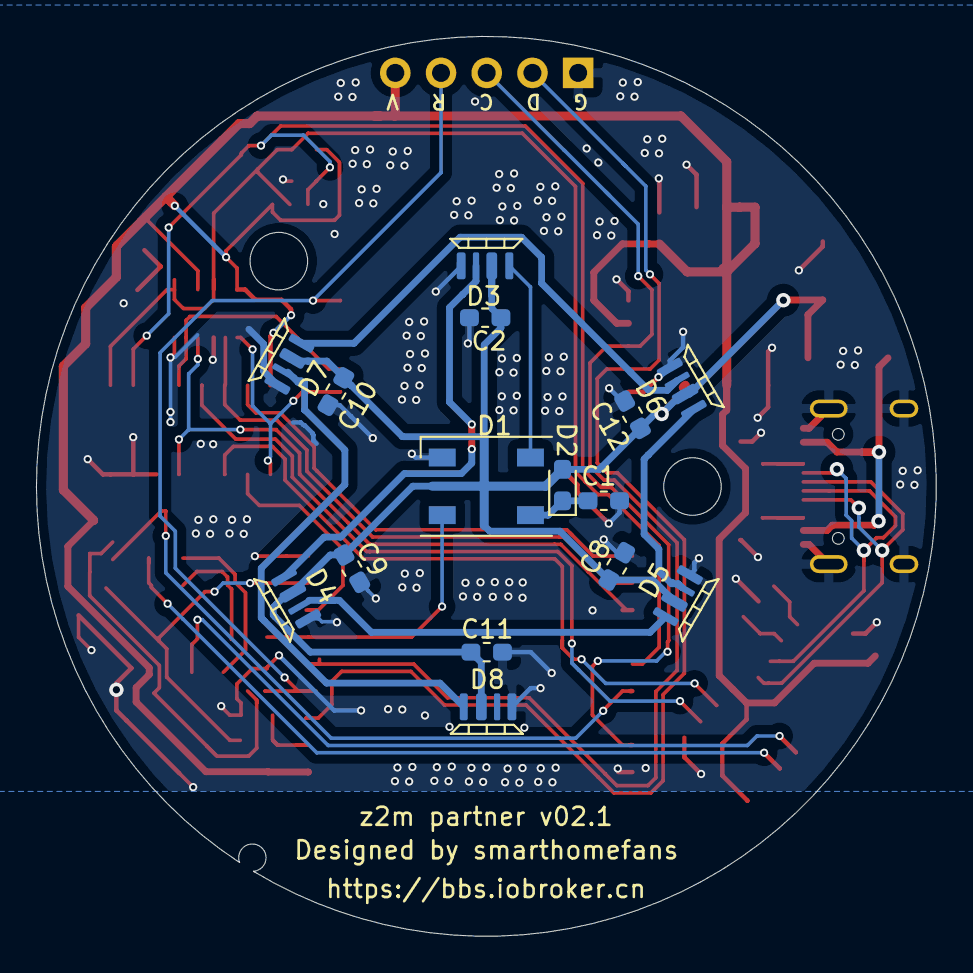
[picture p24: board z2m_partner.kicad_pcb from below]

Board: 2 copper layers, 50.0 x 50.0 mm, 50 parts (15 on the bottom side), 39 nets.

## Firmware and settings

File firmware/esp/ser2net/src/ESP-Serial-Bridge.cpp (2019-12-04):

#include <Arduino.h>
#include "config.h"

#ifdef ESP8266
#include <ESP8266WiFi.h>
#include <ESP8266mDNS.h>
#else
#include <WiFi.h>
#include <ESPmDNS.h>
#endif
#include "FS.h"

#include <ESPAsyncWebServer.h>
#include <PubSubClient.h>
#include <ArduinoOTA.h>
#include <DNSServer.h>
#include <ESPAsyncWiFiManager.h>
#include <ArduinoJson.h>

void callback(char *topic, byte *payload, unsigned int length);

// For debug log output/update FW
#if (DEBUG)
HardwareSerial *DBGCOM = &Serial1;
#define LOGD(...) do {\
  DBGCOM->printf(__VA_ARGS__);\
  DBGCOM->println();\
} while(0)
#else
#define LOGD(...)
#endif

struct Config {
  char hostname[16];
  char ssid[64];
  char password[64];
  int tcpPort;
  char mqttServer[32];
  int mqttPort;
  char mqttUser[32];
  char mqttPass[32];
  char mqttClientID[32];
  char mqttPubTopic[32];
  char mqttSubTopic[32];
};

struct Config config = {
  "z2mp",
  "",
  "",
  8880,
  "",
  1883,
  "",
  "",
  "z2mp",
  "z2mp/result",
  "z2mp/cmd",
};

HardwareSerial *COM = &Serial;

uint8_t buf1[BUFFERSIZE];
uint16_t i1 = 0;

uint8_t buf2[BUFFERSIZE];
uint16_t i2 = 0;

#ifdef PROTOCOL_TCP
#include <WiFiClient.h>
WiFiServer *server;
WiFiClient *TCPClient[MAX_NMEA_CLIENTS];
#endif
PubSubClient *client;

AsyncWebServer wifiManagerServer(80);
DNSServer wifiManagerDNS;

void callback(char *topic, byte *payload, unsigned int length)
{

  byte *p = (byte *)malloc(length);
  memcpy(p, payload, length); // Copy the payload to the new buffer
  client->publish(config.mqttPubTopic, p, length, retained);
  COM->write(p, length); // UART write buffer received via MQTT sub_topic
  free(p);
}

void reconnect()
{
  // Loop until we're reconnected
  while (!client->connected())
  {
    LOGD("Attempting MQTT connection...");
    // Attempt to connect
    if (client->connect(config.mqttServer, config.mqttUser, config.mqttPass))
    {
      // Once connected, publish an announcement...
      client->publish(config.mqttPubTopic, "UART<-->WiFi Bridge Reconnected", false);
      // ... and resubscribe
      client->subscribe(config.mqttSubTopic, qos);
    }
    else
    {
      LOGD("failed, rc=%d try again in 5 seconds.", client->state());
      // Wait 5 seconds before retrying
      delay(5000);
    }
  }
}

static inline void reset_zigbee()
{
  digitalWrite(ZGB_RST_PIN, LOW);
  delay(500);
  digitalWrite(ZGB_RST_PIN, HIGH);
  if (strlen(config.mqttServer) && client->connected()) {
    client->publish(config.mqttPubTopic, "ZNP device reset.", false);
  }
}

static void getConfigFromFile() {

#define READ_STR_CONFIG_FROM_JSON(name) \
if (strlen(doc[#name])) \
  strlcpy(config.name, doc[#name], sizeof(config.name))
#define READ_INT_CONFIG_FROM_JSON(name) \
if (doc[#name]) \
  config.name = doc[#name]

  StaticJsonDocument<512> doc;
  if (!SPIFFS.begin()) {
    LOGD("mount spiffs failed.");
    return;
  }
  File f = SPIFFS.open("/config.json", "r");
  if (!f) {
    LOGD("Config file not exist.");
    SPIFFS.end();
    return;
  }
  DeserializationError error = deserializeJson(doc, f);
  if (error) {
    LOGD("Failed to read file, using default configuration");
    SPIFFS.end();
    return;
  }
  READ_STR_CONFIG_FROM_JSON(hostname);
  READ_STR_CONFIG_FROM_JSON(ssid);
  READ_STR_CONFIG_FROM_JSON(password);
  READ_STR_CONFIG_FROM_JSON(mqttServer);
  READ_STR_CONFIG_FROM_JSON(mqttUser);
  READ_STR_CONFIG_FROM_JSON(mqttPass);
  READ_STR_CONFIG_FROM_JSON(mqttClientID);
  READ_STR_CONFIG_FROM_JSON(mqttPubTopic);
  READ_STR_CONFIG_FROM_JSON(mqttSubTopic);
  READ_INT_CONFIG_FROM_JSON(tcpPort);
  READ_INT_CONFIG_FROM_JSON(mqttPort);
  SPIFFS.end();
}

void setup()
{
  pinMode(TTY_SEL0_PIN, OUTPUT);
  digitalWrite(TTY_SEL0_PIN, LOW);
  pinMode(TTY_SEL1_PIN, OUTPUT);
  digitalWrite(TTY_SEL1_PIN, HIGH);
  delay(500);
#ifdef ESP8266
  COM->begin(UART_BAUD0, SERIAL_PARAM0);
#else
  COM->begin(UART_BAUD0, SERIAL_PARAM0, SERIAL0_RXPIN, SERIAL0_TXPIN);
#endif
#if (DEBUG)
  DBGCOM->begin(115200);
#endif
  LOGD("\n\n WiFi Serial Bridge %d.%d.%d", VERSION_M, VERSION_N, VERSION_P);

  getConfigFromFile();

  if (strlen(config.ssid) == 0)
  {
    LOGD("No SSID defined, use wifi manager.");
    AsyncWiFiManager wifiManager(&wifiManagerServer, &wifiManagerDNS);
#if (DEBUG)
    wifiManager.setDebugOutput(false);
#else
    wifiManager.setDebugOutput(false);
#endif
    wifiManager.autoConnect(config.hostname);
  }
  else
  {
    LOGD("SSID defined, connect to %s", config.ssid);
    WiFi.mode(WIFI_STA);
    WiFi.begin(config.ssid, config.password);
  }
  while (WiFi.status() != WL_CONNECTED)
  {
    delay(500);
    LOGD("Connecting to %s", config.ssid);
  }
  LOGD("TCP server: %s:%d", WiFi.localIP().toString().c_str(), config.tcpPort);

#ifdef PROTOCOL_TCP
  static WiFiServer server_0(config.tcpPort);
  server = &server_0;
#endif
  static WiFiClient mqc;
  static PubSubClient mqttClient(config.mqttServer, config.mqttPort, callback, mqc);
  client = &mqttClient;

  // Enable MDNS
  MDNS.begin(config.hostname);

  // Enable OTA

  ArduinoOTA.setPort(8266);
  ArduinoOTA.setHostname(config.hostname);
  ArduinoOTA.onStart([]() {
    if (ArduinoOTA.getCommand() == U_FLASH)
      LOGD("Start updating sketch");
    else// U_FS
      LOGD("Start updating filesystem");
  });
  ArduinoOTA.onEnd([]() {
    LOGD("\nEnd");
  });
  ArduinoOTA.onProgress([](unsigned int progress, unsigned int total) {
    LOGD("Progress: %u%%\r", (progress / (total / 100)));
  });
  ArduinoOTA.onError([](ota_error_t error) {
    LOGD("Error[%u]: ", error);
    if (error == OTA_AUTH_ERROR)
    {
      LOGD("Auth Failed");
    }
    else if (error == OTA_BEGIN_ERROR)
    {
      LOGD("Begin Failed");
    }
    else if (error == OTA_CONNECT_ERROR)
    {
      LOGD("Connect Failed");
    }
    else if (error == OTA_RECEIVE_ERROR)
    {
      LOGD("Receive Failed");
    }
    else if (error == OTA_END_ERROR)
    {
      LOGD("End Failed");
    }
  });
  ArduinoOTA.begin();

  if (strlen(config.mqttServer) &&
    client->connect(config.mqttServer, config.mqttUser, config.mqttPass)) {
    client->publish(config.mqttPubTopic, "UART<-->WiFi Bridge Connected", false);
    client->publish(config.mqttPubTopic, WiFi.localIP().toString().c_str(), false);
    client->subscribe(config.mqttSubTopic, qos);
  }

#ifdef PROTOCOL_TCP
  LOGD("Starting TCP Server");
  server->begin(); // start TCP server
  server->setNoDelay(true);
#endif

#ifndef ESP8266
  esp_err_t esp_wifi_set_max_tx_power(50); //lower WiFi Power
#endif
  pinMode(ZGB_RST_PIN, OUTPUT);
  digitalWrite(ZGB_RST_PIN, HIGH);
  reset_zigbee();
//  pinMode(12, INPUT);
//  pinMode(13, INPUT);
//  pinMode(14, INPUT);
//  pinMode(16, INPUT);
}

void loop()
{
  if (strlen(config.mqttServer))
  {
    if (!client->connected())
    {
      reconnect();
    }
    client->loop();
  }

#ifdef PROTOCOL_TCP
  for (byte i = 0; i < MAX_NMEA_CLIENTS; i++)
  {
    //find disconnected spot
    if (TCPClient[i] && !TCPClient[i]->connected())
    {
      TCPClient[i]->stop();
      delete TCPClient[i];
      TCPClient[i] = NULL;
      LOGD("Client disconnected");
    }
  }
  if (server->hasClient())
  {
    for (byte i = 0; i < MAX_NMEA_CLIENTS; i++)
    {
      //find free/disconnected spot
      if (!TCPClient[i] || !TCPClient[i]->connected())
      {
        if (TCPClient[i])
        {
          TCPClient[i]->stop();
          delete TCPClient[i];
          TCPClient[i] = NULL;
          LOGD("Client disconnected");
        }
        TCPClient[i] = new WiFiClient;
        *TCPClient[i] = server->available();
        LOGD("New client for COM");
        continue;
      }
    }
    //no free/disconnected spot so reject
    WiFiClient TmpserverClient = server->available();
    TmpserverClient.stop();
  }
#endif

  if (COM != NULL)
  {
    for (byte cln = 0; cln < MAX_NMEA_CLIENTS; cln++)
    {
      if (TCPClient[cln])
      {
        while (TCPClient[cln]->available())
        {
          buf1[i1] = TCPClient[cln]->read(); // read char from TCP port:8880
          if (i1 < BUFFERSIZE - 1)
            i1++;
        }
        if (i1 > 0)
        {
          COM->write(buf1, i1); // now send to UART
#if (DEBUG)
          DBGCOM->printf("TX(%d):\t", i1);
          for (int i = 0; i < i1; i++)
            DBGCOM->printf("%02x ", buf1[i]);
          DBGCOM->println();
#endif
          i1 = 0;
        }
      }
    }

    if (COM->available())
    {
      while (COM->available())
      {
        buf2[i2] = COM->read(); // read char from UART
        if (i2 < BUFFERSIZE - 1)
          i2++;
      }
      // now send to WiFi:
      for (byte cln = 0; cln < MAX_NMEA_CLIENTS; cln++)
      {
        if (TCPClient[cln])
          TCPClient[cln]->write(buf2, i2); //send the buffer to TCP port:8880
      }
      if (strlen(config.mqttServer))
      {
        client->publish(config.mqttPubTopic, buf2, i2, retained); //Publish the buffer received via serial
      }
#if (DEBUG)
        DBGCOM->printf("RX(%d):\t", i2);
        for (int i = 0; i < i2; i++)
          DBGCOM->printf("%02x ", buf2[i]);
        DBGCOM->println();
#endif
      i2 = 0;
    }
  }

#ifdef ESP8266
  MDNS.update();
#endif
  ArduinoOTA.handle();
}

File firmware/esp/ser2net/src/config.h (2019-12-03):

// config: ////////////////////////////////////////////////////////////
#ifndef _ESP_SERIAL_BRIDGE_CONFIG_H_
#define _ESP_SERIAL_BRIDGE_CONFIG_H_

#define PROTOCOL_TCP
#ifndef MAX_NMEA_CLIENTS
#define MAX_NMEA_CLIENTS 1
#endif

unsigned char qos = 1; //subscribe qos
bool retained = false;

#define ZGB_RST_PIN     12
#define TTY_SEL0_PIN    16
#define TTY_SEL1_PIN    5
/*************************  COM Port 0 *******************************/
#define UART_BAUD0 115200        // Baudrate UART0
#ifdef ESP8266
#define SERIAL_PARAM0 SERIAL_8N1 // Data/Parity/Stop UART0
#else
#define SERIAL_PARAM0 SERIAL_8N1 // Data/Parity/Stop UART0
#define SERIAL0_RXPIN 21         // receive Pin UART0
#define SERIAL0_TXPIN 1          // transmit Pin UART0
#endif

#define BUFFERSIZE 1024

#endif

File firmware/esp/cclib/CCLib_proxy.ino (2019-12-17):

/*
 ///////////////////////////////////////////////////////////////////////////////
 This example demonstrates the use of the CCDebugger class from CCLib.

 This is the firmware you must flash in your Wemos D1 Mini if you want to use
 the python library that comes with this project.

 ///////////////////////////////////////////////////////////////////////////////
 (C) Copyright 2014, Ioannis Charalampidis - Licensed under GNU/GPLv3 License.
 (C) Copyright 2015, Simon Schulz - github.com/fishpepper
 ///////////////////////////////////////////////////////////////////////////////
 */

////////////////////////////////////////
////////////////////////////////////////

// Pinout configuration (Configured for Tasmota Zigbee)
int CC_RST   = 12;
int CC_DC    = 13;
int CC_DD    = 14;
int SEL_0    = 16;
int SEL_1    = 5;

////////////////////////////////////////
////////////////////////////////////////

// Include the CCDebugger
#include "CCDebugger.h"

// Command constants
#define   CMD_ENTER     byte(0x01)
#define   CMD_EXIT      byte(0x02)
#define   CMD_CHIP_ID   byte(0x03)
#define   CMD_STATUS    byte(0x04)
#define   CMD_PC        byte(0x05)
#define   CMD_STEP      byte(0x06)
#define   CMD_EXEC_1    byte(0x07)
#define   CMD_EXEC_2    byte(0x08)
#define   CMD_EXEC_3    byte(0x09)
#define   CMD_BRUSTWR   byte(0x0A)
#define   CMD_RD_CFG    byte(0x0B)
#define   CMD_WR_CFG    byte(0x0C)
#define   CMD_CHPERASE  byte(0x0D)
#define   CMD_RESUME    byte(0x0E)
#define   CMD_HALT      byte(0x0F)
#define   CMD_PING      byte(0xF0)
#define   CMD_INSTR_VER byte(0xF1)
#define   CMD_INSTR_UPD byte(0xF2)

// Response constants
#define   ANS_OK       byte(0x01)
#define   ANS_ERROR    byte(0x02)
#define   ANS_READY    byte(0x03)

// Initialize properties
CCDebugger * dbg;
byte inByte, bAns, bIdle;
byte c1, c2, c3;
unsigned short s1;
int iLen, iRead;

/**
 * Initialize debugger
 */
void setup() {

  // Set USB tty to ESP
  pinMode(SEL_0, OUTPUT);
  pinMode(SEL_1, OUTPUT);
  digitalWrite(SEL_0, HIGH);
  digitalWrite(SEL_1, LOW);

  // Create debugger
  dbg = new CCDebugger( CC_RST, CC_DC, CC_DD );

  // Initialize serial port
  Serial.begin(115200);

  // Wait for chip to initialize
  delay(100);

  // Enter debug mode
  dbg->enter();

}

/**
 * Send a response frame
 */
void sendFrame( const byte ans, const byte b0=0, const byte b1=0 ) {
    Serial.write(ans);
    Serial.write(b1); // Send High-order first
    Serial.write(b0); // Send Low-order second
    Serial.flush();
}

/**
 * Check if debugger is in error state and if yes,
 * reply with an error code.
 */
boolean handleError( ) {
  if (dbg->error()) {
    sendFrame(ANS_ERROR, dbg->error());
    return true;
  }
  return false;
}

/**
 * Main program loop
 */
void loop() {

  // Wait for incoming data frame
  if (Serial.available() < 4)
    return;

  // Read input frame
  inByte = Serial.read();
      c1 = Serial.read();
      c2 = Serial.read();
      c3 = Serial.read();

  // Handle commands
  if (inByte == CMD_PING) {
    sendFrame( ANS_OK );

  } else if (inByte == CMD_ENTER) {
    bAns = dbg->enter();
    if (handleError()) return;
    sendFrame( ANS_OK );

  } else if (inByte == CMD_EXIT) {
    bAns = dbg->exit();
    if (handleError()) return;
    sendFrame( ANS_OK );

  } else if (inByte == CMD_CHIP_ID) {
    s1 = dbg->getChipID();
    if (handleError()) return;
    sendFrame( ANS_OK,
               s1 & 0xFF,       // LOW first
               (s1 >> 8) & 0xFF // HIGH second
              );

  } else if (inByte == CMD_PC) {
    s1 = dbg->getPC();
    if (handleError()) return;
    sendFrame( ANS_OK,
               s1 & 0xFF,       // LOW first
               (s1 >> 8) & 0xFF // HIGH second
              );

  } else if (inByte == CMD_STATUS) {
    bAns = dbg->getStatus();
    if (handleError()) return;
    sendFrame( ANS_OK, bAns );

  } else if (inByte == CMD_HALT) {
    bAns = dbg->halt();
    if (handleError()) return;
    sendFrame( ANS_OK, bAns );

  } else if (inByte == CMD_EXEC_1) {

    bAns = dbg->exec( c1 );
    if (handleError()) return;
    sendFrame( ANS_OK, bAns );

  } else if (inByte == CMD_EXEC_2) {

    bAns = dbg->exec( c1, c2 );
    if (handleError()) return;
    sendFrame( ANS_OK, bAns );

  } else if (inByte == CMD_EXEC_3) {
    bAns = dbg->exec( c1, c2, c3 );
    if (handleError()) return;
    sendFrame( ANS_OK, bAns );

  } else if (inByte == CMD_BRUSTWR) {

    // Calculate the size of the incoming brust
    iLen = (c1 << 8) | c2;

    // Validate length
    if (iLen > 2048) {
      sendFrame( ANS_ERROR, 3 );
      return;
    }

    // Confirm transfer
    sendFrame( ANS_READY );

    // Prepare for brust-write
    dbg->write( 0x80 | (c1 & 0x07) ); // High-order bits
    dbg->write( c2 ); // Low-order bits

    // Start serial loop
    iRead = iLen;
    bIdle = 0;
    while (iRead > 0) {

      // When we have data, forward them to the debugger
      if (Serial.available() >= 1) {
        inByte = Serial.read();
        dbg->write(inByte);
        bIdle = 0;
        iRead--;
      }

      // If we don't have any data, check for idle timeout
      else {

        // If we are idle for more than 3s, drop command
        if (++bIdle > 3000) {

          // The PC was disconnected/stale for too long
          // complete the command by sending 0's
          while (iRead > 0) {
            dbg->write(0);
            iRead--;
          }

          // Read debug status to complete the command sequence
          dbg->switchRead();
          bAns = dbg->read();
          dbg->switchWrite();

          // Send error
          sendFrame( ANS_ERROR, 4 );
          return;

        }

        // Wait for some time
        delay(1);

      }
    }

    // Read debug status
    dbg->switchRead();
    bAns = dbg->read();
    dbg->switchWrite();

    // Handle response
    if (handleError()) return;
    sendFrame( ANS_OK, bAns );

  } else if (inByte == CMD_RD_CFG) {
    bAns = dbg->getConfig();
    if (handleError()) return;
    sendFrame( ANS_OK, bAns );

  } else if (inByte == CMD_WR_CFG) {
    bAns = dbg->setConfig(c1);
    if (handleError()) return;
    sendFrame( ANS_OK, bAns );

  } else if (inByte == CMD_CHPERASE) {
    bAns = dbg->chipErase();
    if (handleError()) return;
    sendFrame( ANS_OK, bAns );

  } else if (inByte == CMD_STEP) {
    bAns = dbg->step();
    if (handleError()) return;
    sendFrame( ANS_OK, bAns );

  } else if (inByte == CMD_RESUME) {
    bAns = dbg->resume();
    if (handleError()) return;
    sendFrame( ANS_OK, bAns );

  } else if (inByte == CMD_INSTR_VER) {
    bAns = dbg->getInstructionTableVersion();
    if (handleError()) return;
    sendFrame( ANS_OK, bAns );

  } else if (inByte == CMD_INSTR_UPD) {

    // Acknowledge transfer
    sendFrame( ANS_READY );

    // Read 16 bytes from the input
    byte instrBuffer[16];
    iRead = 0;
    while (iRead < 16) {
      if (Serial.available() >= 1) {
        instrBuffer[iRead++] = Serial.read();
      }
    }
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

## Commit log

2019-10-27 sch first version
    [z2m_partner.kicad_pcb, z2m_partner.sch]
2019-10-27 assign footprints
    [z2m_partner.sch]
2019-10-27 Update e18 footprint
    [z2m_partner.sch]
2019-10-27 layout finish
    [z2m_partner.kicad_pcb, z2m_partner.sch]
2019-10-28 Update silk
    [z2m_partner.kicad_pcb]
2019-10-28 add guide
    [z2m_partner.kicad_pcb]
2019-10-28 Add gerber files
    [z2m_partner-B_Cu.gbr, z2m_partner-B_Mask.gbr, z2m_partner-B_Paste.gbr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]
2019-11-09 Move kicad project to folder
    [z2m_partner-B_Cu.gbr, z2m_partner-B_Mask.gbr, z2m_partner-B_Paste.gbr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]
2019-11-18 Update to v02
    [z2m_partner-B_Cu.gbr, z2m_partner-B_Mask.gbr, z2m_partner-B_Paste.gbr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]
2019-11-18 Add rgb led datasheet
2019-11-19 update file structure
    [z2m_partner-B_Cu.gbr, z2m_partner-B_Mask.gbr, z2m_partner-B_Paste.gbr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]
2019-11-24 Add v01 3d cover
    [Zigbee网关-A.STL, Zigbee网关-B.STL, Zigbee网关-C.STL]
2019-11-24 check spiffs mount status
2019-11-24 Fix spiffs mount issue
    [ESP-Serial-Bridge.cpp]
2019-11-28 Update version to v02.1
    [z2m_partner-Bottom_Cu.gbr, z2m_partner-Bottom_Mask.gbr, z2m_partner-Bottom_Paste.gbr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]
2019-12-03 remove old geber
    [z2m_partner-B_Cu.gbr, z2m_partner-B_Mask.gbr, z2m_partner-B_Paste.gbr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]
2019-12-03 set select pin in code
2019-12-16 update bom
2019-12-17 fix sel pin-mode
2019-12-20 修复中文文档连接
2020-01-08 Add v2p1 3D cave
    [Zigbee网关-A.STL, Zigbee网关-B.STL, Zigbee网关-C.STL]
